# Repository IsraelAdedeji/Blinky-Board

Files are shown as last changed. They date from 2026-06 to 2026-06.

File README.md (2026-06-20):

# Blinky-Board
A custom PCB designed to blink LEDs at variable speeds and intervals
My first PCB. Its a butterfly, aint that cool?

# Image






# Schematic, Footprint Mapping and PCB Design Image







# Bill Of Materials
[Blinky Board-bom (2).csv](https://github.com/user-attachments/files/29165458/Blinky.Board-bom.2.csv)

| Name | Purpose | Quantity | Total Cost (USD) | Link | Distributor |
|---:|---|---|---|---|---:|
| Potentiometer | Gets range input | 1 | 0.00 | https://www.aliexpress.com/item/1005012093971113.html | Aliexpress |
| LEDs | Emitting Light With Current | 0 | 0.00 | https://www.aliexpress.com/item/1005008040796418.html | Aliexpress |
| Capacitors | Stores Electrical Energy | 2 | 0.00 | https://www.aliexpress.com/item/1005005558643765.html | Aliexpress |
| Controller IC (CD4017) | IC to control LEDS | 1 | 0.00 | https://www.aliexpress.com/item/1005010146574961.html | Aliexpress |
| Timer IC (NE555N) | Controls timing of led blinks | 1 | 0.00 | https://www.aliexpress.com/item/32821209180.html | Aliexpress |
| Resistors | Resists Current Flow | 3 | 0.00 | https://www.aliexpress.com/item/32847096736.html | Aliexpress |
| PCB | Its the PCB for the project | 1 | 2.00 | https://cart.jlcpcb.com | JLCPCB |

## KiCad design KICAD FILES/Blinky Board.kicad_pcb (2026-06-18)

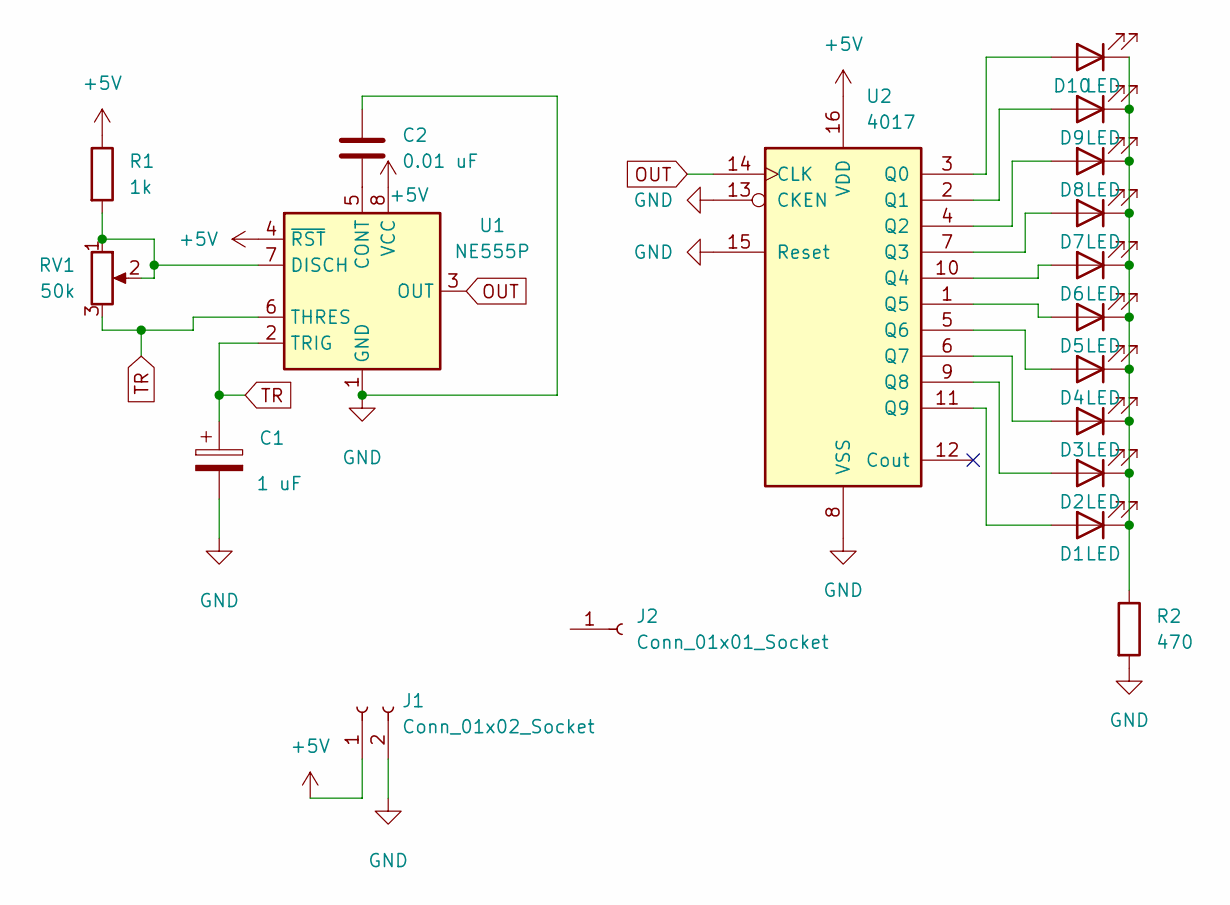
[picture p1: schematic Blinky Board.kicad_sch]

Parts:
C1: 1 uF; CP_Radial_D5.0mm_P2.00mm
C2: 0.01 uF; C_Disc_D7.5mm_W2.5mm_P5.00mm
D1, D2, D3, D4, D5, D6, D7, D8, D9, D10: LED; LED_D3.0mm
J1: Conn_01x02_Socket; PinHeader_1x02_P2.54mm_Vertical
J2: Conn_01x01_Socket; PinHeader_1x01_P2.54mm_Vertical
R1: 1k; R_Axial_DIN0207_L6.3mm_D2.5mm_P7.62mm_Horizontal
R2: 470; R_Axial_DIN0207_L6.3mm_D2.5mm_P7.62mm_Horizontal
RV1: 50k; Potentiometer_Vishay_T93YA_Vertical
U1: NE555P; DIP-8_W7.62mm
U2: 4017; N16

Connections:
+5V: J1.1, R1.1, U1.4 (~RST), U1.8 (VCC), U2.16 (VDD)
GND: C1.2, C2.2, J1.2, R2.2, U1.1 (GND), U2.8 (VSS), U2.13 (CKEN), U2.15 (Reset)
unnamed: D1.2 (A), U2.11 (Q9)
unnamed: D1.1 (K), D2.1 (K), D3.1 (K), D4.1 (K), D5.1 (K), D6.1 (K), D7.1 (K), D8.1 (K), D9.1 (K), D10.1 (K), R2.1
unnamed: D2.2 (A), U2.9 (Q8)
unnamed: D3.2 (A), U2.6 (Q7)
unnamed: D4.2 (A), U2.5 (Q6)
unnamed: D5.2 (A), U2.1 (Q5)
unnamed: D6.2 (A), U2.10 (Q4)
unnamed: D7.2 (A), U2.7 (Q3)
unnamed: D8.2 (A), U2.4 (Q2)
unnamed: D9.2 (A), U2.2 (Q1)
unnamed: D10.2 (A), U2.3 (Q0)
unnamed: C2.1, U1.5 (CONT)
unnamed: R1.2, RV1.1, RV1.2, U1.7 (DISCH)
OUT: U1.3 (OUT), U2.14 (CLK)
TR: C1.1, RV1.3, U1.2 (TRIG), U1.6 (THRES)

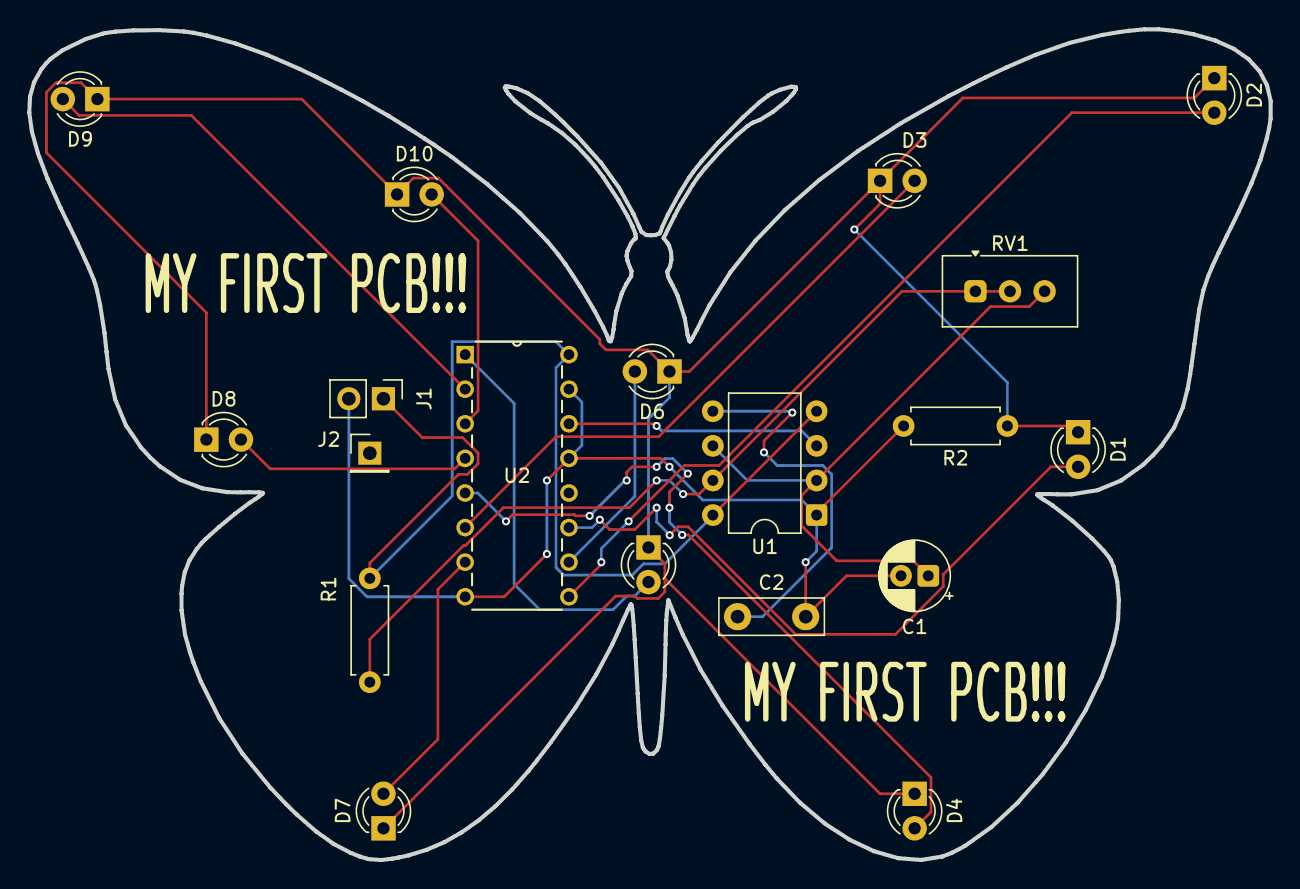
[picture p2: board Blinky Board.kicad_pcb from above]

Board: 2 copper layers, 91.1 x 61.0 mm, 19 parts (0 on the bottom side), 17 nets.

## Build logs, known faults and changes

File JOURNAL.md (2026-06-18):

[Uploading JOURNAL (13).md…]()
<!--
  This journal is auto generated by Stasis.
-->

# 6/18/2026 10 PM - PCB Design

_Time spent: 4h_

# Overview
This is my very first PCB project. Following the tutorial, i did everything That was needed but not without some issues obviously. For example, I didnt want to make any basic shape, so i went down the rabbit hole of trying to figure out how to get custom shapes in kicad. Turns out the dxf converter i was trying to use was a bit glitchy so it kept ruining my pcb outline. After several attempts i was able to get it to work.
Then another thing was routing the traces. Honestly, I was made to believe it was a pain and hard to do but i actually enjoyed it, well... most of it anyways. well, i guess i shouldnt feel too over confident since this IS a beginner project, theres probably harder versions but who knows for now.



I made it in a butterfly shape, pretty neat huh
The issue of traces crossing... that was actually a problem though, but only minor which was mostly my fault since i moved the components after i had already routed them.
Anyways... I guess thats it, My First PCB!!!

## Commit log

2026-06-18 Fix BOM.csv formatting and update PCB entry
2026-06-19 Update and rename KICAD FILES/F to KICAD FILES/EXTRAS/Footprint Mapping
2026-06-19 Revise Bill of Materials in README.md
    Updated the Bill of Materials with new components and links.
